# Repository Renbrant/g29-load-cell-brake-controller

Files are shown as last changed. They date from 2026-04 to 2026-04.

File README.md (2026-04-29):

# G29 Load Cell Brake Controller (G29PB v2.0)

A high-performance load cell brake upgrade for the Logitech G29, designed to deliver realistic, pressure-based braking with precision, consistency, and adjustability.

<p align="center">
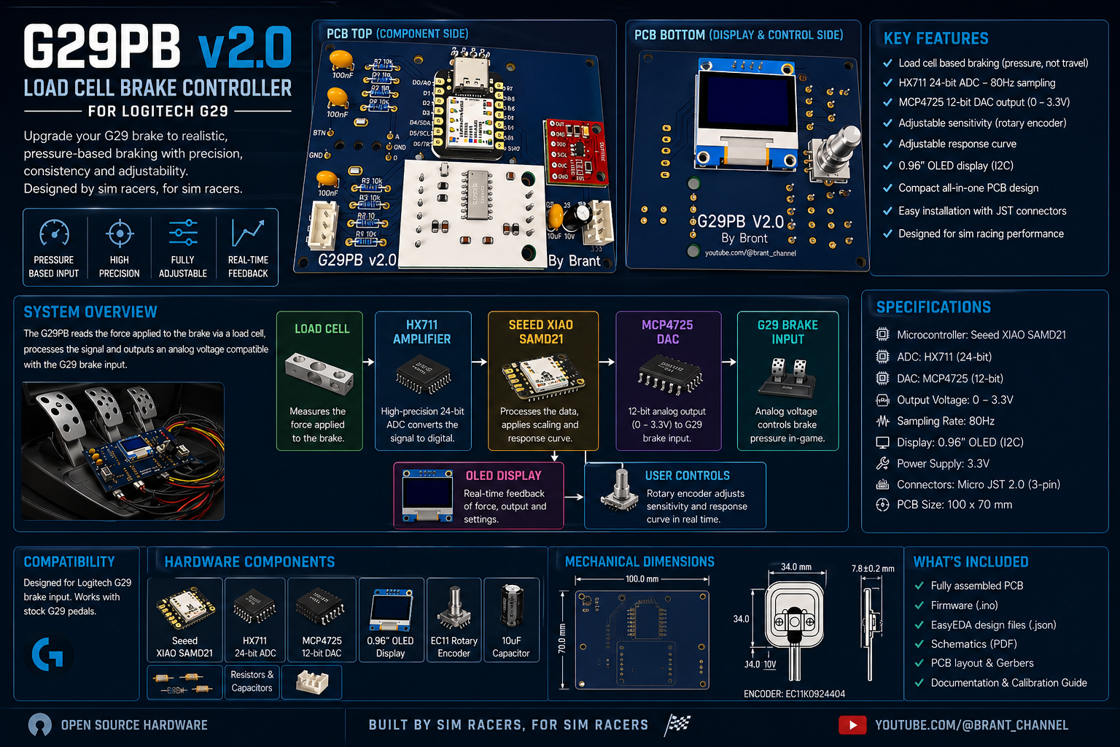
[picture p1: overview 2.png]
  
</p>

---

## 🚀 Overview

The G29PB replaces the stock potentiometer-based brake with a load cell system, transforming braking from position-based input into pressure-based control.

This results in:

* More realistic braking feel
* Better consistency lap after lap
* Improved muscle memory and control

---

## 📸 Hardware

<p align="center">
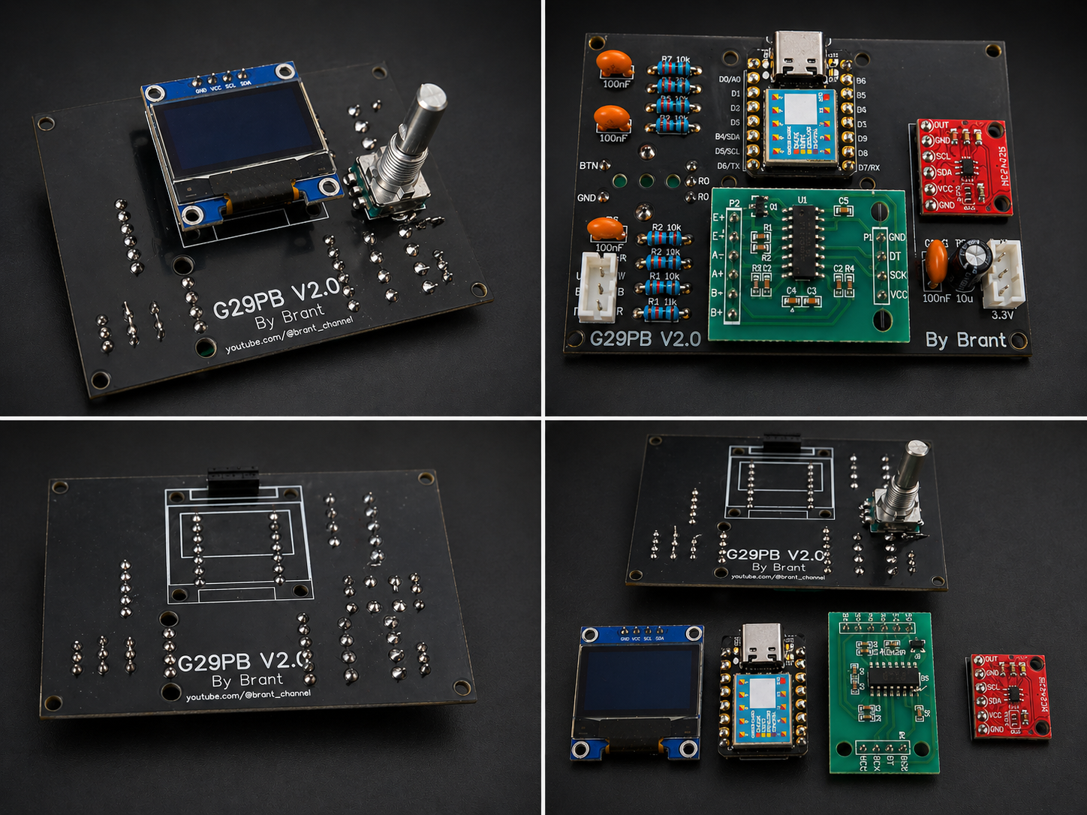
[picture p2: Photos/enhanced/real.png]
  
</p>

### PCB Top Layer

<p align="center">
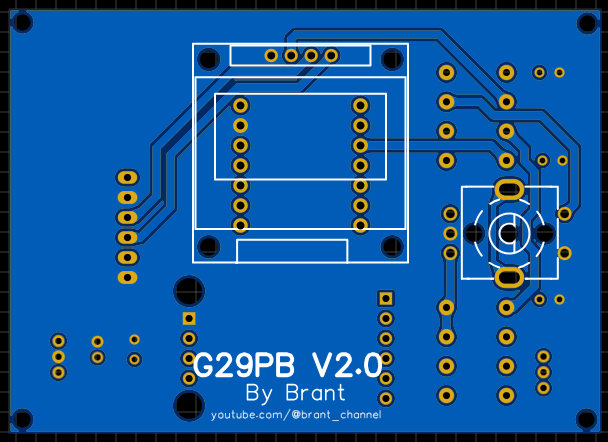
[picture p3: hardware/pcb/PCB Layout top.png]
  
</p>

### PCB Bottom Layer

<p align="center">
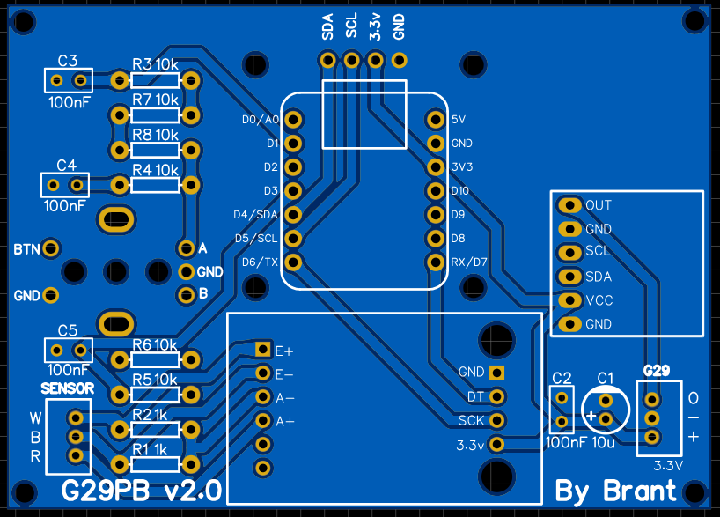
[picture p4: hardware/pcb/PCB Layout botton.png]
  
</p>

---

## 🔥 Key Features

* Load cell-based braking (pressure instead of travel)
* HX711 amplifier with high-speed sampling (80Hz)
* 12-bit analog output via MCP4725 DAC (0–3.3V)
* Adjustable sensitivity via potentiometer
* Adjustable response curve shaping
* Real-time feedback via OLED display
* Compact all-in-one PCB design
* Clean wiring with dedicated connectors

---

## 🧰 Hardware Architecture

* Arduino Nano
* HX711 Load Cell Amplifier
* MCP4725 DAC
* 128x64 OLED Display (I2C)
* Potentiometers:

  * Sensitivity adjustment
  * Curve shaping

---

## 🧠 Design Philosophy

This project prioritizes:

* Fast response over extreme precision
* Driver consistency over raw measurement accuracy
* Simple and reliable calibration
* Hardware-based adjustments (no need to reflash firmware)

---

## 🔌 PCB Design

* Version: **G29PB v2.0**
* Compact and integration-friendly layout
* Optimized routing for signal stability
* Decoupling capacitors for noise reduction
* Dedicated connectors for easy installation

---

## ⚙️ Firmware

Located in `/firmware`

Main features:

* Real-time load cell reading (80Hz)
* Dynamic scaling of input force
* DAC output mapping (0–3.3V)
* Adjustable behavior via potentiometers
* OLED visualization of braking response

---

## 🧪 Calibration

See `/calibration/procedures.md`

Highlights:

* Repeatable manual calibration process
* Stable readings prioritized over absolute precision
* No EEPROM dependency (simplified system)

---

## 🧩 3D Printed Load Cell Adapter

To properly integrate the load cell into the G29 pedal, a custom 3D-printed adapter is used.

<p align="center">
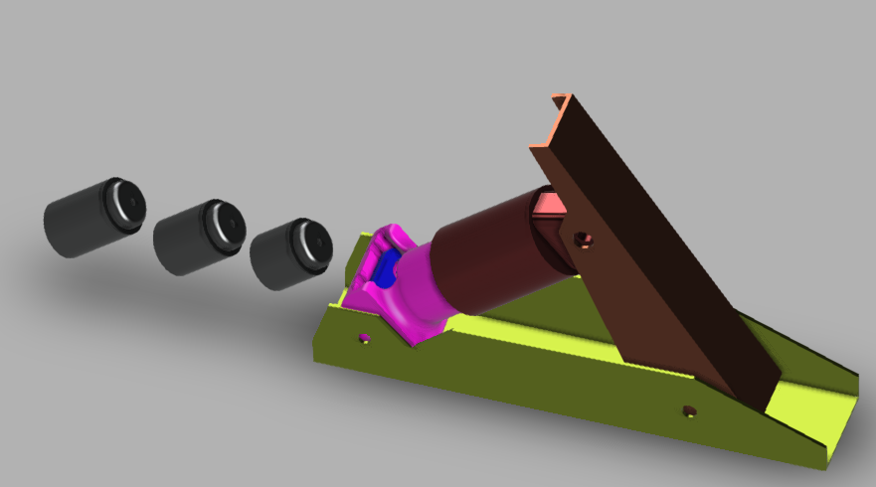
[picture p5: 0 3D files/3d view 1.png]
  
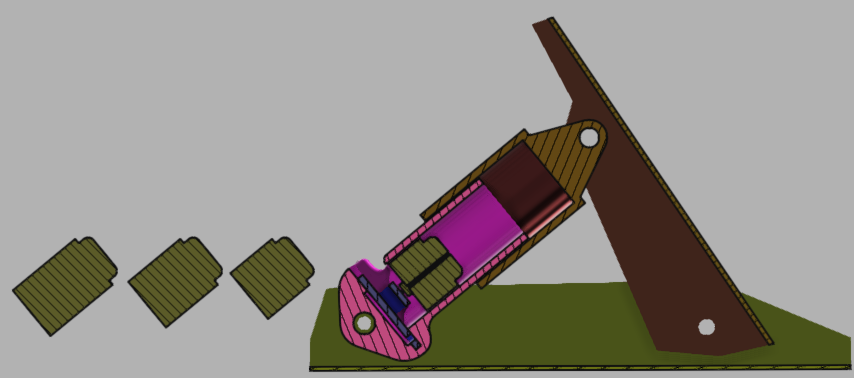
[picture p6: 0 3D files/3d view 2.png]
  
</p>

<p align="center">
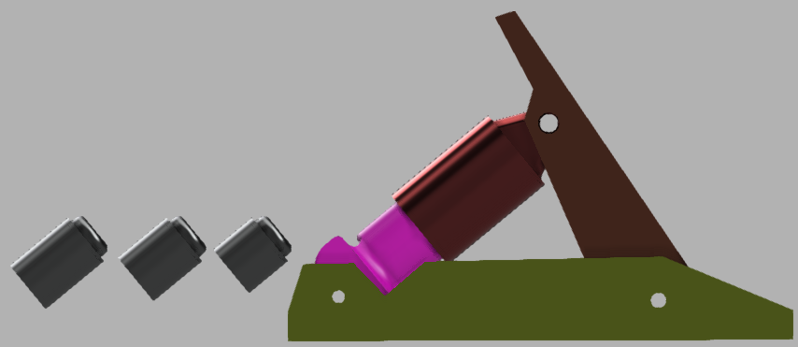
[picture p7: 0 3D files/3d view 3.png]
  
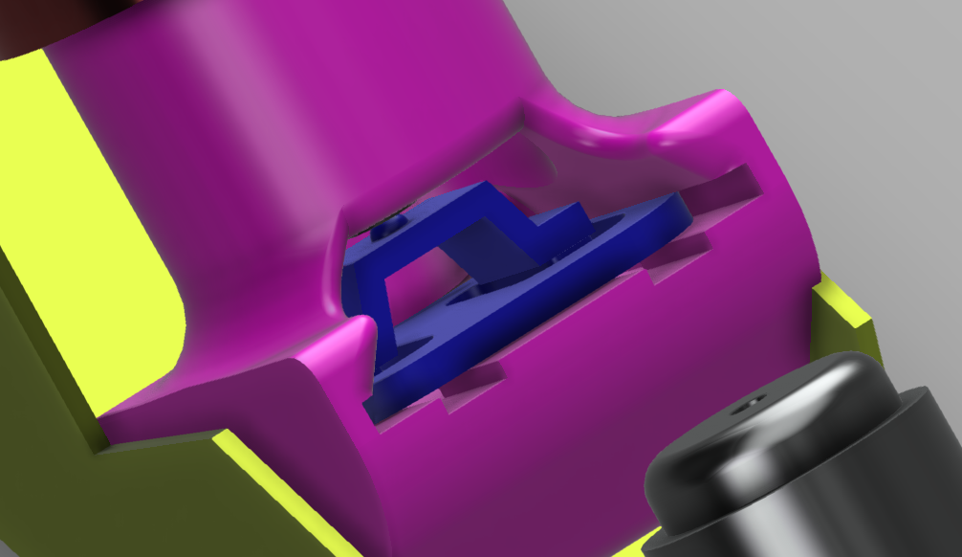
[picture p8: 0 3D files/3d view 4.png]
  
</p>

### 🖨️ 3D Printing Files

All STL files required for printing are available in:

```
/0 3D files/
```

---

## 📦 Repository Contents

* Firmware source code (.ino)
* EasyEDA design files (.json)
* Schematics (PDF)
* PCB layout and Gerbers
* 3D models and STL files
* Documentation and calibration guide

---

## 🎯 Use Case

Designed for sim racers who want:

* Realistic braking feel
* Better trail braking control
* Consistency under pressure
* A DIY solution with professional-level performance

---

## 🤝 Contributing

Contributions are welcome.
Feel free to fork, improve, and share your version.

---

## 📄 License

Licensed under the Apache License 2.0

---

## ❤️ Support the Project

If you found this project useful, consider supporting:

* Subscribe: https://youtube.com/@brant_channel
* Share your build with the community

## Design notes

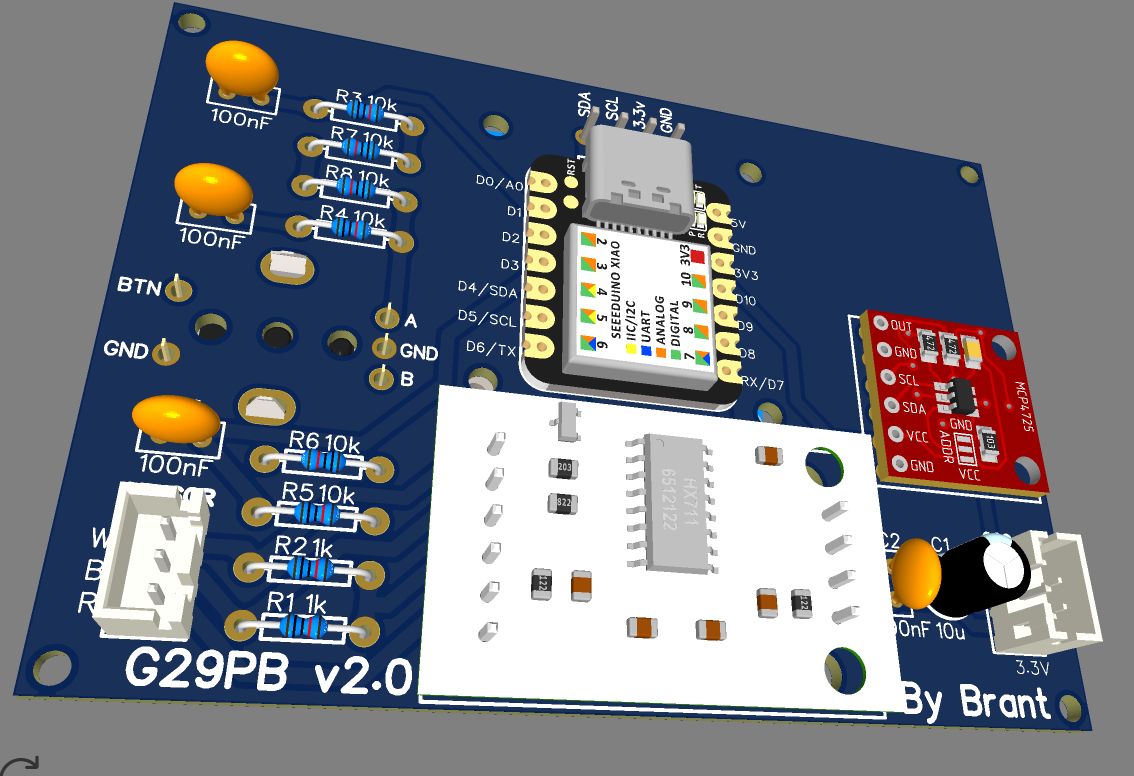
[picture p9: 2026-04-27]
hardware/pcb/PCB 3d view 1.png

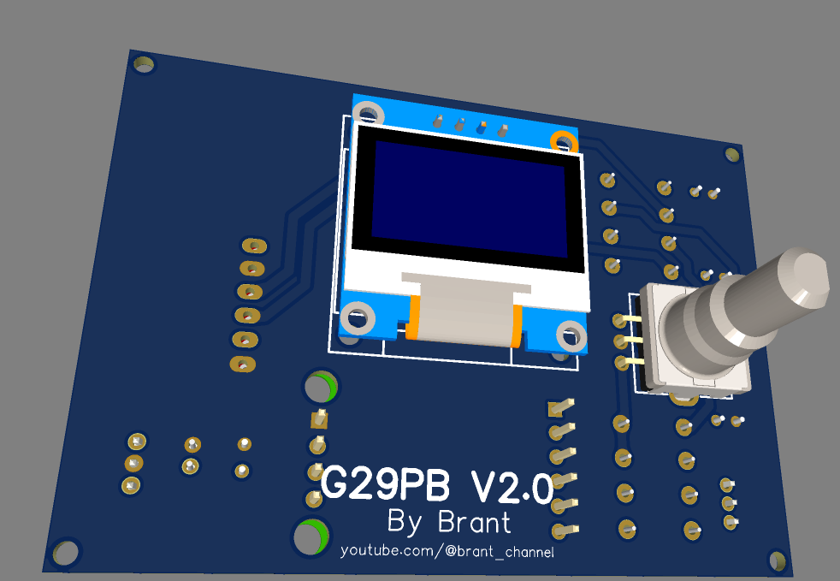
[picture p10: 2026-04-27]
hardware/pcb/PCB 3d view 2.png

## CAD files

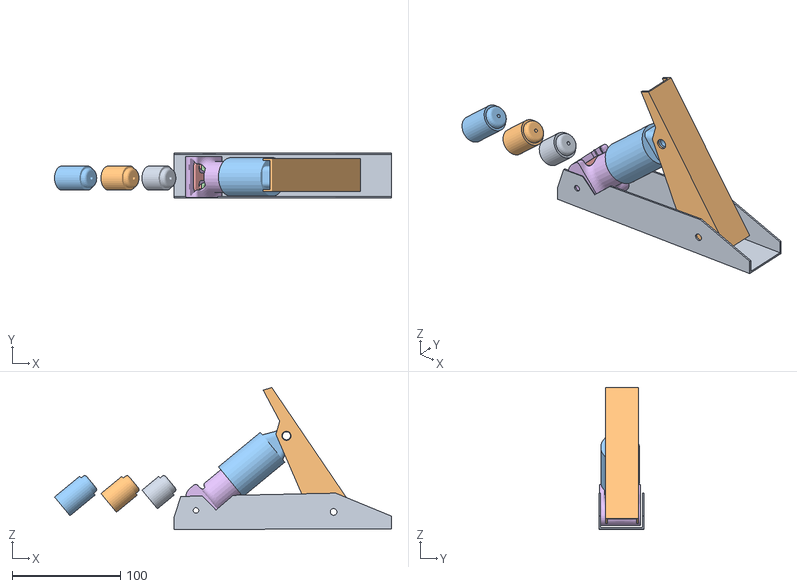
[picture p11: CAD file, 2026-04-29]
0 3D files/G29BS.obj
311.0 x 41.9 x 131.0
50kg load cell (1)
50kg load cell (1) (1)

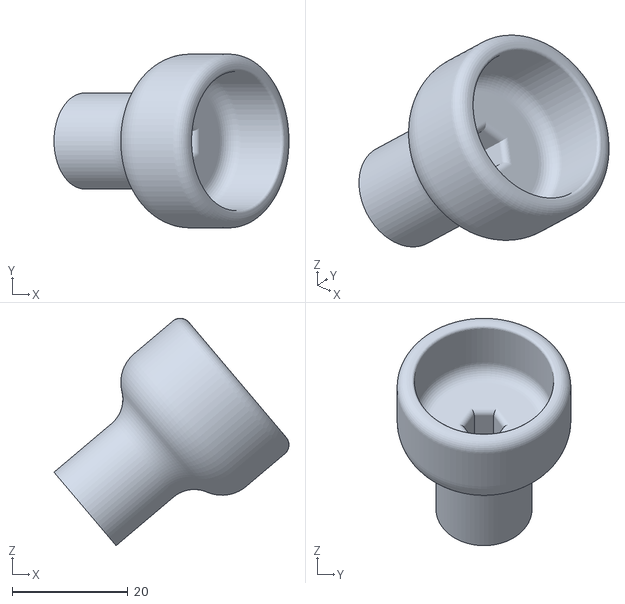
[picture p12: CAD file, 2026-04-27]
0 3D files/Pistao interno v2.stl
40.6 x 30.0 x 39.2

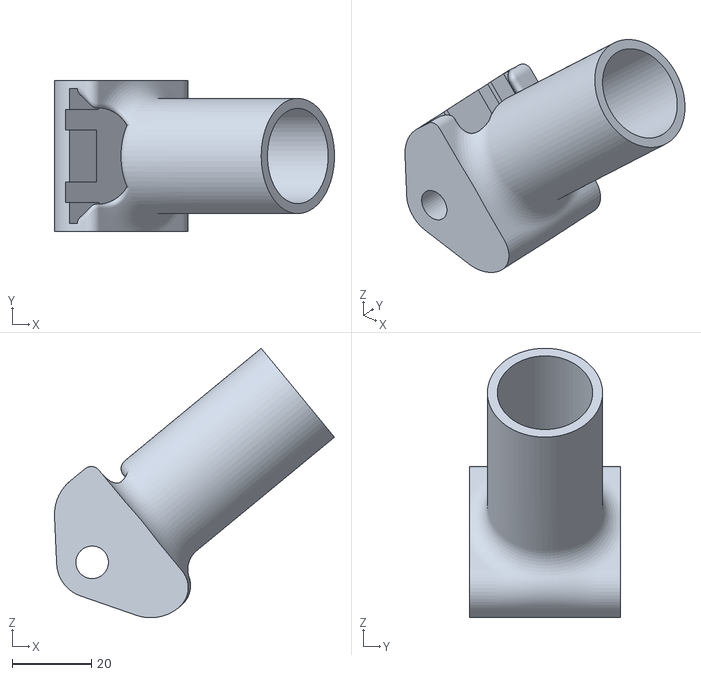
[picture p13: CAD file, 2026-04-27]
0 3D files/Porta sensor v3.stl
70.5 x 38.0 x 67.8

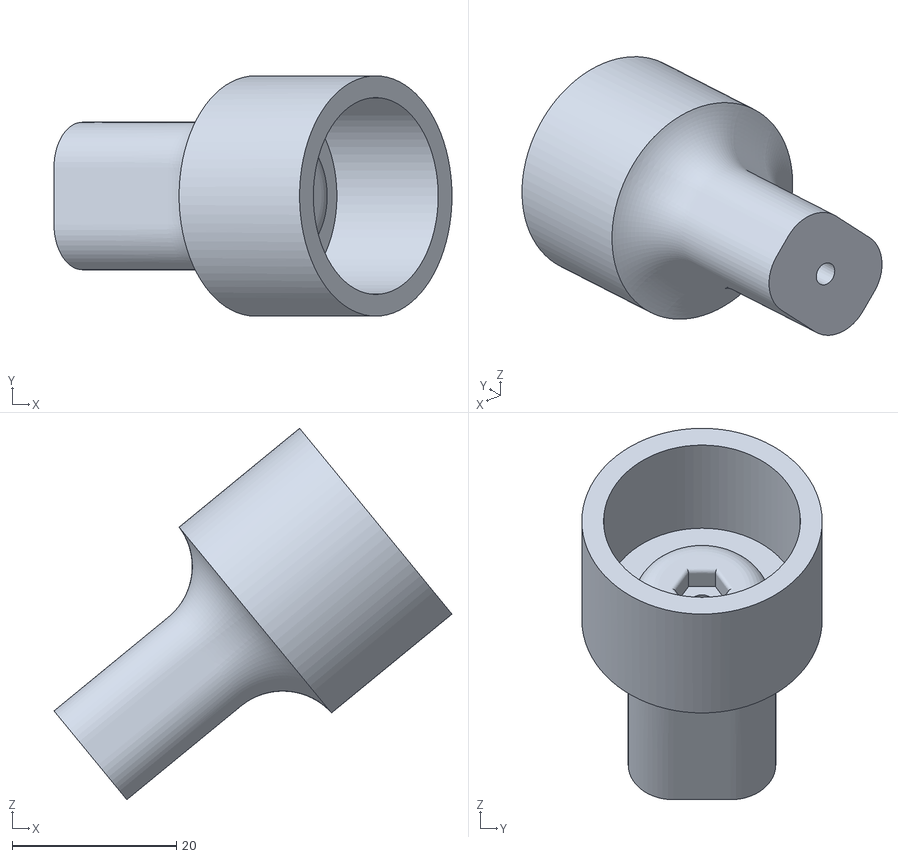
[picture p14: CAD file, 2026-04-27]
0 3D files/Cilindro central.stl
48.5 x 29.3 x 45.3

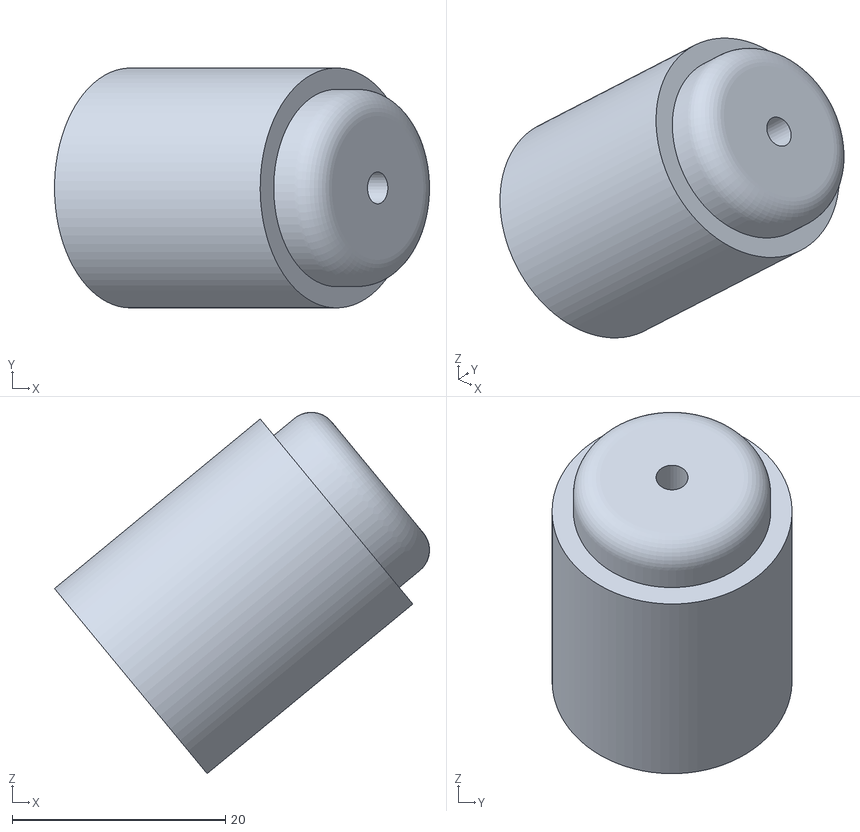
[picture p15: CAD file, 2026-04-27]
0 3D files/Pistao c v3.stl
35.2 x 22.5 x 33.9

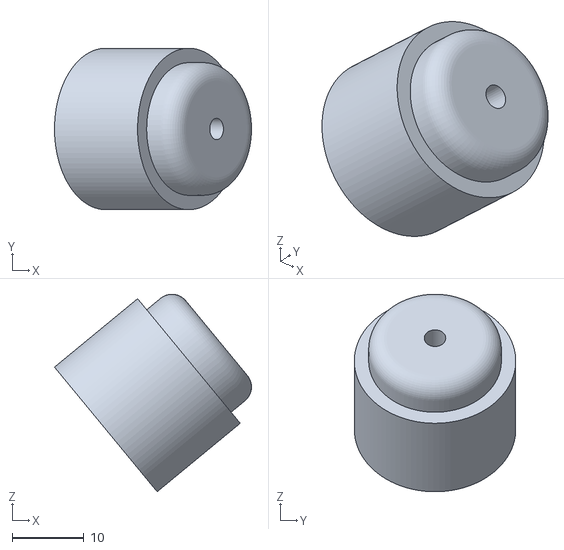
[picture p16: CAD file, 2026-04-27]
0 3D files/Pistao a v3.stl
27.5 x 22.5 x 27.5

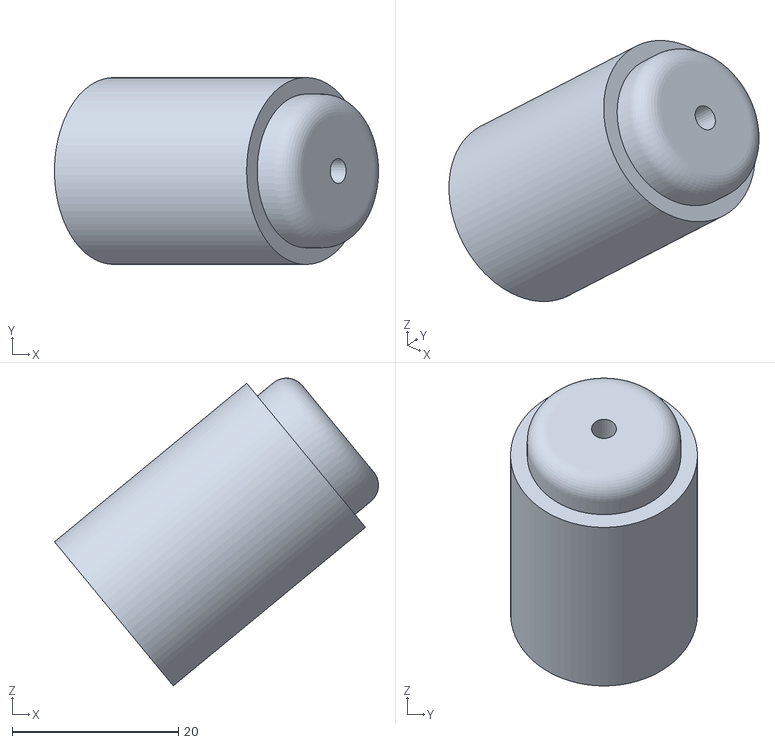
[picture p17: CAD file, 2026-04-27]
0 3D files/Pistao d v3.stl
39.0 x 22.5 x 37.1

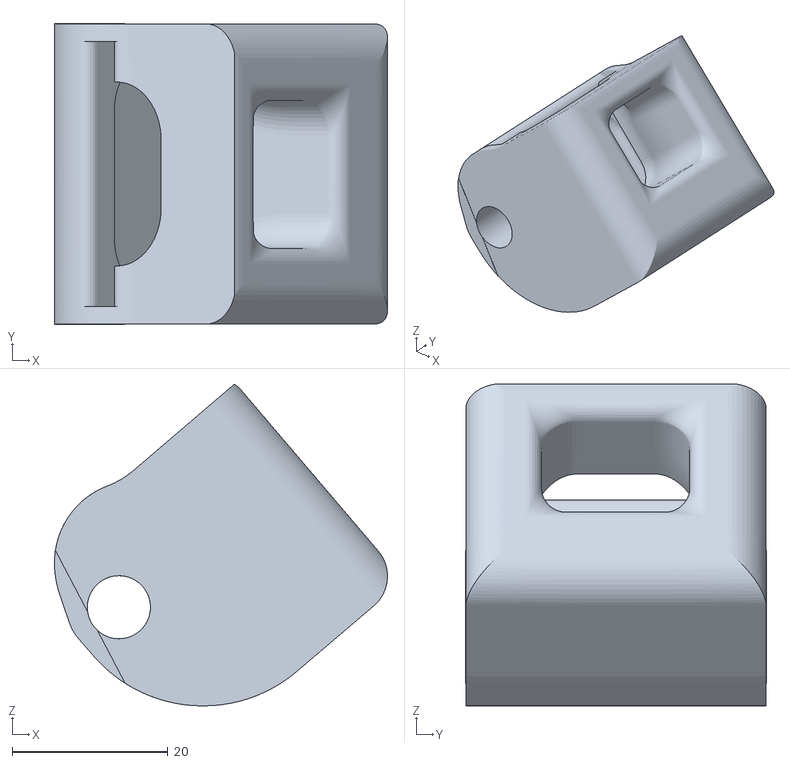
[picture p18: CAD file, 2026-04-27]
0 3D files/Porta sensor.stl
42.7 x 38.6 x 41.3

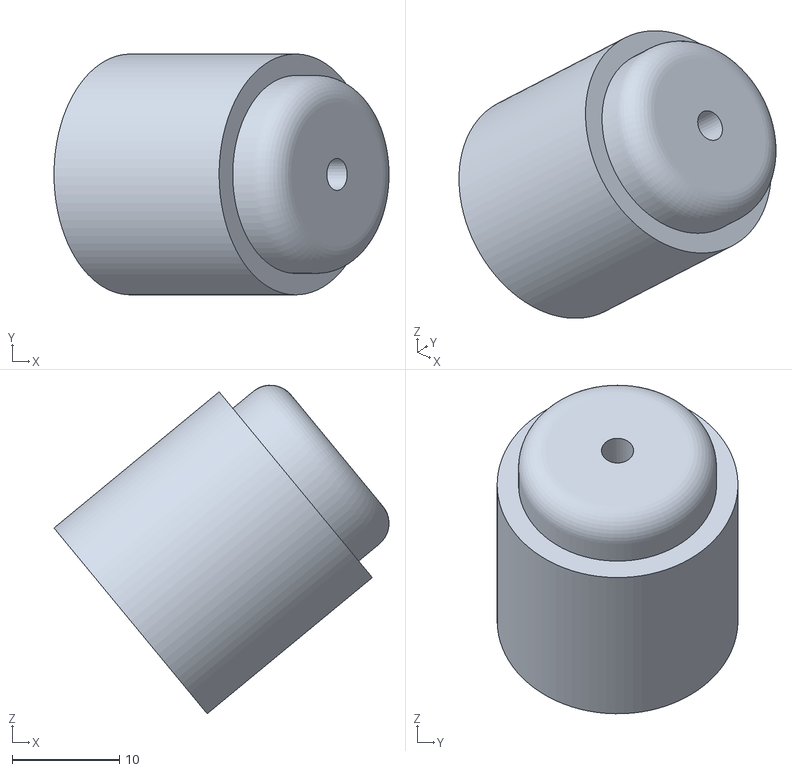
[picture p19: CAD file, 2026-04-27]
0 3D files/Pistao b v3.stl
31.3 x 22.5 x 30.7

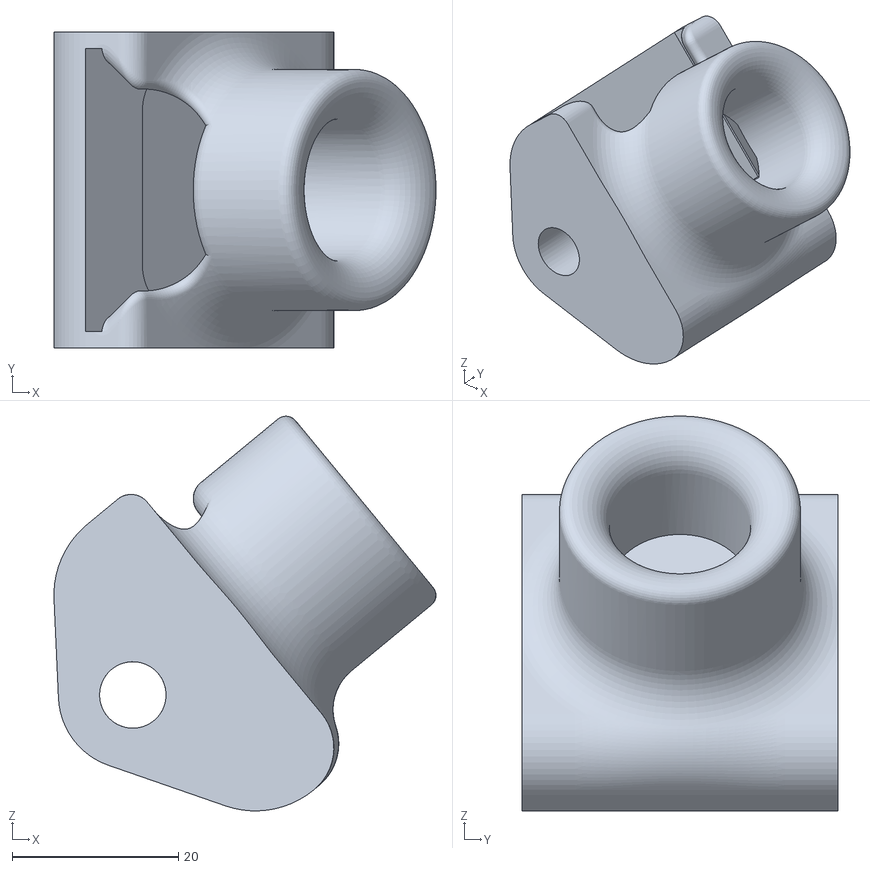
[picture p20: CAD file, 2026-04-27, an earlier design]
0 3D files/Porta sensor v2.stl
45.9 x 38.0 x 47.5

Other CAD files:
0 3D files/Porta sensor (1).stl
0 3D files/G29BS.f3d
0 3D files/Pistao interno v2.f3d
0 3D files/Porta sensor v2.f3d
0 3D files/rear_wheel_axle (1).f3d

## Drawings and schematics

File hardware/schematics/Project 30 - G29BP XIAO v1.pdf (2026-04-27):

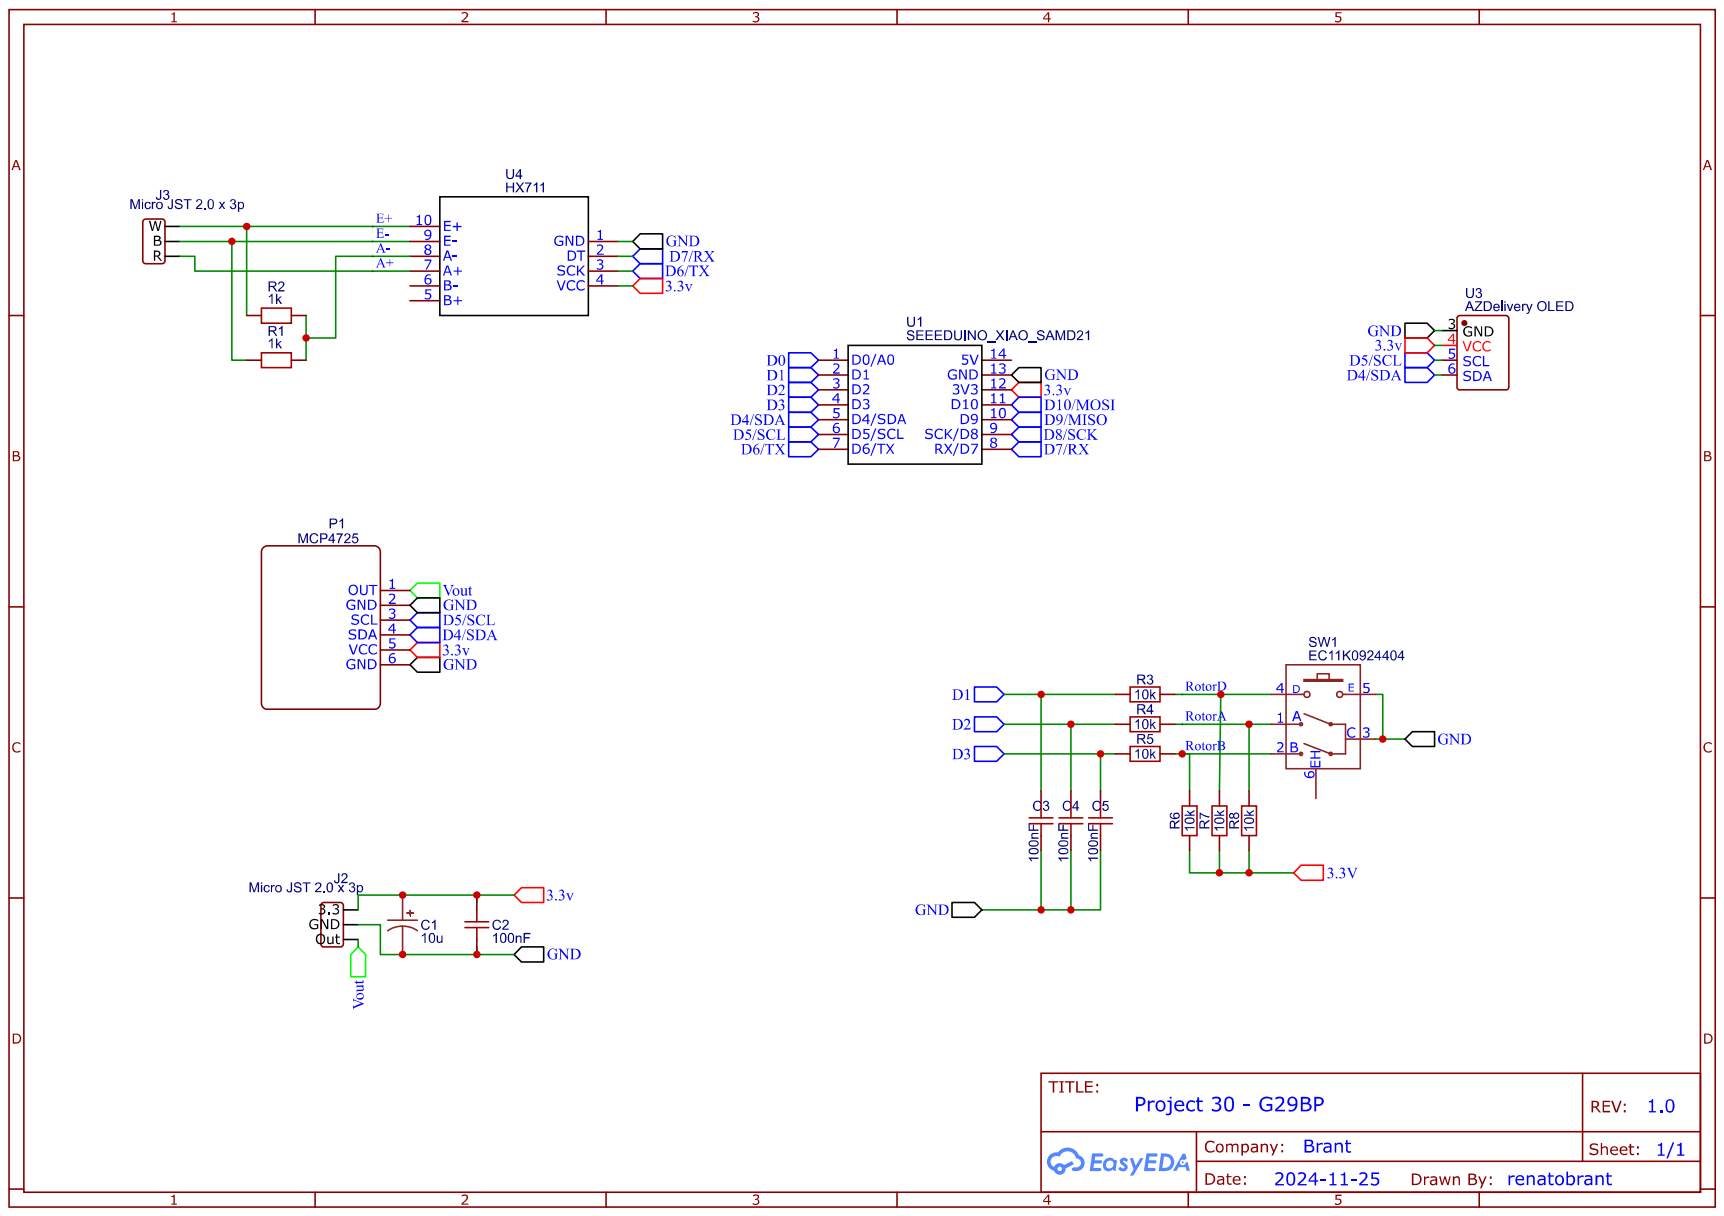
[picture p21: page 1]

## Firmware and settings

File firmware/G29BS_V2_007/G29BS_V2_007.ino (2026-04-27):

/*
  Programa: Simulador de Freio com Saída Analógica
  Autor: Renato Brant
  Data: 01/12/2024
  Versão: v2.007

  Histórico de Modificações:
  - v2.004: Alterado o comportamento do cálculo de curva de tensão para inverter a relação pressão/tensão.
  - v2.005: Corrigido o problema de apresentação do gráfico que ignorava o MIN_VOLTAGE (1.47V).
           Excluída a configuração do formato da curva devido a inconsistências. Agora o comportamento é estritamente linear.
           Criado um histórico de modificações para acompanhamento de versões.
  - v2.006: Refatoração para melhorar a organização e legibilidade do código sem alterar funcionalidades existentes.
           Adicionado ajuste do valor mínimo de tensão (Vmin).
           Valores de Vmax e Vmin exibidos no display (canto inferior esquerdo e superior direito, respectivamente).
           Quadrado desenhado ao redor do valor que está sendo configurado.
           Movida a apresentação da pressão para o canto inferior direito, acima do valor de tensão (previousVoltage).
           Fundo preto adicionado para os valores de pressão e tensão para melhor contraste.
  - v2.007: Melhorada a interface gráfica do ajuste de configurações.
           Menu de configurações exibido no canto superior esquerdo apenas quando o botão é pressionado.
           Opções: Inclinação (I), Vmax e Vmin, com destaque `>` para a configuração ativa.
           Menu desaparece automaticamente após 5 segundos de inatividade, salvando as configurações.
           Corrigido valor no display para sincronizar com a saída DAC.
           Expandido o controle de curva para maior sensibilidade a pressões menores (curva mais inclinada).
*/

#include <Wire.h>
#include <Adafruit_MCP4725.h>
#include <HX711.h>
#include <Adafruit_GFX.h>
#include <Adafruit_SSD1306.h>
#include <Encoder.h>
#include <FlashStorage.h>

// Definições dos pinos
#define DT_PIN 7
#define SCK_PIN 6
#define ROTARY_CLK_PIN 1
#define ROTARY_DT_PIN 2
#define ROTARY_SW_PIN 3
#define OLED_RESET -1

// Objetos para os periféricos
HX711 scale;
Adafruit_MCP4725 dac;
Adafruit_SSD1306 display(128, 64, &Wire, OLED_RESET);
Encoder rotaryEncoder(ROTARY_CLK_PIN, ROTARY_DT_PIN);

// Estrutura para armazenar configurações
struct Config {
  float maxVoltage;  // Tensão máxima ajustável
  float minVoltage;  // Tensão mínima ajustável
  float curveFactor; // Fator de inclinação da curva
};
FlashStorage(flashConfig, Config); // Aloca espaço na memória flash

// Configurações iniciais padrão
float maxVoltage = 3.3;           // Tensão máxima inicial
float minVoltage = 1.47;          // Tensão mínima inicial
float curveFactor = 0.0;          // Inclinação inicial da curva
int lastEncoderPosition = 0;      // Última posição do encoder
bool buttonPressed = false;       // Estado do botão do encoder
int configMode = 0;               // 0 = Inclinação, 1 = Vmax, 2 = Vmin

// Configuração do HX711
const float CALIBRATION_FACTOR = -44.765419; // Fator de calibração para o sensor
const long OFFSET = 1877599;                 // Offset para ajustar o zero
float pressure = 0;                          // Pressão medida em kg

// Controle gráfico
const int GRAPH_WIDTH = 122;                 // Largura do gráfico
const int GRAPH_HEIGHT = 64;                 // Altura do gráfico

float outputVoltage = 0;                     // Tensão de saída calculada

// Controle do menu de configurações
bool showConfigMenu = false;                 // Controla a exibição do menu de configurações
unsigned long lastInteraction = 0;           // Tempo da última interação
const unsigned long CONFIG_TIMEOUT = 5000;   // Tempo limite para esconder o menu (5 segundos)

// Função: Configuração inicial do sistema
void setup() {
  Serial.begin(115200);
  Serial.println("Iniciando sistema...");

  // Inicializa HX711
  scale.begin(DT_PIN, SCK_PIN);
  scale.set_offset(OFFSET);
  scale.set_scale(CALIBRATION_FACTOR);

  // Inicializa DAC MCP4725
  dac.begin(0x60);

  // Inicializa display OLED
  display.begin(SSD1306_SWITCHCAPVCC, 0x3C);
  display.clearDisplay();
  display.setTextSize(1);
  display.setTextColor(WHITE);
  display.display();

  // Configura botão do encoder
  pinMode(ROTARY_SW_PIN, INPUT_PULLUP);

  // Carrega configurações salvas na memória flash
  loadSettings();

  Serial.println("Sistema inicializado com sucesso!");
}

// Função: Laço principal do programa
void loop() {
  handleButtonPress();     // Gerencia as interações do botão
  handleEncoderRotation(); // Processa a movimentação do encoder

  // Esconde o menu de configuração após o tempo limite
  if (showConfigMenu && millis() - lastInteraction > CONFIG_TIMEOUT) {
    showConfigMenu = false;
    saveSettings();
    Serial.println("Configurações salvas automaticamente após inatividade.");
  }

  // Lê e atualiza os dados do sistema
  if (scale.is_ready()) {
    pressure = readPressure(); // Lê a pressão do sensor
    updateDAC();               // Atualiza a saída do DAC
    updateDisplay();           // Atualiza a tela OLED
  }
}

// Função: Lê o estado do botão do encoder
void handleButtonPress() {
  bool currentButtonState = digitalRead(ROTARY_SW_PIN) == LOW;
  if (currentButtonState && !buttonPressed) {
    if (!showConfigMenu) {
      showConfigMenu = true; // Ativa o menu de configurações
    } else {
      configMode = (configMode + 1) % 3; // Alterna entre Inclinação, Vmax e Vmin
    }
    lastInteraction = millis(); // Atualiza o tempo de interação
  }
  buttonPressed = currentButtonState;
}

// Função: Lê o movimento do encoder e ajusta as configurações
void handleEncoderRotation() {
  if (showConfigMenu) { // Permite ajustes apenas quando o menu está ativo
    int newEncoderPosition = rotaryEncoder.read() / 2; // Divide por 2 para maior controle
    if (newEncoderPosition != lastEncoderPosition) {
      int delta = newEncoderPosition - lastEncoderPosition;

      if (configMode == 0) { // Ajusta a Inclinação
        curveFactor += delta * 0.05;
        curveFactor = constrain(curveFactor, -2.0, 2.0); // Limites expandidos
      } else if (configMode == 1) { // Ajusta o Vmax
        maxVoltage += delta * 0.05;
        maxVoltage = constrain(maxVoltage, 2.5, 3.3);
      } else if (configMode == 2) { // Ajusta o Vmin
        minVoltage += delta * 0.05;
        minVoltage = constrain(minVoltage, 1.0, maxVoltage - 0.1);
      }

      lastEncoderPosition = newEncoderPosition;
      lastInteraction = millis(); // Atualiza o tempo de interação
    }
  }
}

// Função: Lê a pressão do sensor HX711
float readPressure() {
  float measuredPressure = scale.get_units() / 1000.0; // Converte para kg
  return constrain(measuredPressure, 0.0, 50.0); // Limita a pressão entre 0 e 50 kg
}

// Função: Calcula e aplica a tensão ao DAC
void updateDAC() {
  float normalizedPressure = pressure / 50.0; // Normaliza a pressão (0 a 1)
  normalizedPressure = constrain(normalizedPressure, 0.0, 1.0);

  float adjustedPressure = normalizedPressure * (1.0 + curveFactor);
  adjustedPressure = constrain(adjustedPressure, 0.0, 1.0);

  // Calcula a tensão de saída
  outputVoltage = minVoltage + (1.0 - adjustedPressure) * (maxVoltage - minVoltage);

  // Converte para 12 bits e atualiza o DAC
  uint16_t dacOutput = (uint16_t)((outputVoltage / 3.3) * 4095);
  dac.setVoltage(dacOutput, false);
}

// Função: Atualiza o display OLED com os dados mais recentes
void updateDisplay() {
  display.clearDisplay();
  drawGraph();

  if (showConfigMenu) { // Exibe o menu de configurações, se ativo
    display.setTextSize(1);
    display.setCursor(0, 0);
    display.setTextColor(WHITE);
    display.print(configMode == 0 ? "> I: " : "  I: ");
    display.println(curveFactor, 2);
    display.print(configMode == 1 ? "> Vmax: " : "  Vmax: ");
    display.println(maxVoltage, 2);
    display.print(configMode == 2 ? "> Vmin: " : "  Vmin: ");
    display.println(minVoltage, 2);
  } else { // Exibe os valores principais
    display.setCursor(0, 0);
    display.setTextSize(2);
    display.print(String(pressure, 0));
    display.setTextSize(1);
    display.print("kg");

    display.fillRect(66, 48, 58, 16, BLACK);
    display.setCursor(66, 48);
    display.setTextSize(2);
    display.print(String(outputVoltage, 2));
    display.setTextSize(1);
    display.print("V");
  }

  display.display();
}

// Função: Desenha o gráfico de curva no display
void drawGraph() {
  for (int x = 0; x < GRAPH_WIDTH; x++) {
    float rawPos = (float)x / GRAPH_WIDTH;
    float curveY = rawPos * (1.0 + curveFactor);
    float voltage = minVoltage + curveY * (maxVoltage - minVoltage);
    float normalizedVoltage = (voltage - minVoltage) / (maxVoltage - minVoltage);
    int y = constrain(GRAPH_HEIGHT - (normalizedVoltage * GRAPH_HEIGHT), 0, GRAPH_HEIGHT - 1);

    display.drawPixel(x, y, WHITE);
    if (rawPos <= pressure / 50.0) {
      display.drawLine(x, GRAPH_HEIGHT - 1, x, y, WHITE);
    }
  }
}

// Função: Salva as configurações na memória flash
void saveSettings() {
  Config config = {maxVoltage, minVoltage, curveFactor};
  flashConfig.write(config);
  Serial.println("Configurações salvas na memória flash.");
}

// Função: Carrega as configurações da memória flash
void loadSettings() {
  Config config = flashConfig.read();
  maxVoltage = config.maxVoltage;
  minVoltage = config.minVoltage;
  curveFactor = config.curveFactor;

  if (maxVoltage < 2.5 || maxVoltage > 3.3) maxVoltage = 3.3;
  if (minVoltage < 1.0 || minVoltage >= maxVoltage) minVoltage = 1.47;
  if (curveFactor < -2.0 || curveFactor > 2.0) curveFactor = 0.0;

  Serial.print("Configurações carregadas: Vmax=");
  Serial.print(maxVoltage, 2);
  Serial.print("V, Vmin=");
  Serial.print(minVoltage, 2);
  Serial.print("V, Inclinação=");
  Serial.println(curveFactor, 2);
}

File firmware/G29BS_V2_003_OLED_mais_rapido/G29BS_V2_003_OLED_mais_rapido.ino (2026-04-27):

#include <Wire.h>
#include <Adafruit_MCP4725.h>
#include <HX711.h>
#include <Adafruit_GFX.h>
#include <Adafruit_SSD1306.h>
#include <Encoder.h>
#include <FlashStorage.h> // Substituição da EEPROM

// Definições dos pinos
#define DT_PIN 7
#define SCK_PIN 6
#define ROTARY_CLK_PIN 1
#define ROTARY_DT_PIN 2
#define ROTARY_SW_PIN 3
#define OLED_RESET -1

// Objetos para os periféricos
HX711 scale;
Adafruit_MCP4725 dac;
Adafruit_SSD1306 display(128, 64, &Wire, OLED_RESET);
Encoder rotaryEncoder(ROTARY_CLK_PIN, ROTARY_DT_PIN);

// Estrutura para armazenar configurações
struct Config {
  float maxVoltage;
  float curveFactor;
  float curveShape;
};
FlashStorage(flashConfig, Config); // Aloca espaço na flash

// Configuração inicial
float maxVoltage = 3.3;           // Tensão máxima inicial
float curveFactor = 0.0;          // Fator de curva inicial
float curveShape = 0.0;           // Formato da curva inicial (0 = linear)
int lastEncoderPosition = 0;
bool buttonPressed = false;
int configMode = 0; // 0 = Vmax, 1 = Curva, 2 = Formato da Curva

// Configuração do HX711
const float CALIBRATION_FACTOR = -44.765419; // Fator de calibração
const long OFFSET = 1877599;                 // Offset para zero
float pressure = 0;                          // Pressão medida em kg

// Dados do gráfico
const int GRAPH_WIDTH = 122;      // Largura do gráfico
const int GRAPH_HEIGHT = 64;      // Altura do gráfico
const float MIN_VOLTAGE = 1.47;   // Tensão mínima fixa para o MCP4725

float previousPressure = 0;       // Última pressão registrada para comparação

void setup() {
  Serial.begin(115200);
  Serial.println("Iniciando sistema...");

  // Inicializa HX711
  scale.begin(DT_PIN, SCK_PIN);
  scale.set_offset(OFFSET);
  scale.set_scale(CALIBRATION_FACTOR);

  // Inicializa DAC MCP4725
  dac.begin(0x60);

  // Inicializa display OLED
  display.begin(SSD1306_SWITCHCAPVCC, 0x3C);
  display.clearDisplay();
  display.setTextSize(1);
  display.setTextColor(WHITE);
  display.display();

  // Configura botão do encoder
  pinMode(ROTARY_SW_PIN, INPUT_PULLUP);

  // Carrega configurações da flash
  loadSettings();

  Serial.println("Sistema inicializado com sucesso!");
}

void loop() {
  // Leitura do estado do botão do encoder
  bool currentButtonPressed = digitalRead(ROTARY_SW_PIN) == LOW;
  if (currentButtonPressed && !buttonPressed) {
    configMode = (configMode + 1) % 3; // Alterna entre Vmax, Curva e Formato
    saveSettings(); // Salva as configurações na flash
    Serial.println(configMode == 0 ? "Ajustando Vmax" : configMode == 1 ? "Ajustando Curva" : "Ajustando Formato");
  }
  buttonPressed = currentButtonPressed;

  // Leitura do encoder rotativo
  int newEncoderPosition = rotaryEncoder.read() / 2; // Divide por 2 para maior controle
  if (newEncoderPosition != lastEncoderPosition) {
    int delta = newEncoderPosition - lastEncoderPosition;

    if (configMode == 0) {
      maxVoltage += delta * 0.05; // Incrementa ou decrementa em passos de 0.05
      maxVoltage = constrain(maxVoltage, 2.5, 3.3);
    } else if (configMode == 1) {
      curveFactor += delta * 0.01; // Incrementa ou decrementa em passos de 0.01
      curveFactor = constrain(curveFactor, -1.0, 1.0);
    } else if (configMode == 2) {
      curveShape += delta * 0.1; // Incrementa ou decrementa em passos de 0.1
      curveShape = constrain(curveShape, -1.0, 1.0);
    }

    lastEncoderPosition = newEncoderPosition;
  }

  // Leitura da pressão do pedal
  if (scale.is_ready()) {
    pressure = scale.get_units() / 1000.0; // Converte para kg
    pressure = constrain(pressure, 0.0, 50.0); // Limita a pressão entre 0 e 50 kg

    // Atualiza a saída do DAC
    updateDAC();

    // Atualiza o display sincronizado com a leitura
    updateDisplay();
  }
}

void updateDAC() {
  // Normaliza a pressão (0 a 1)
  float normalizedPressure = pressure / 50.0; // Pressão máxima de 50 kg
  normalizedPressure = constrain(normalizedPressure, 0.0, 1.0);

  // Aplica o formato da curva (exponencial ou inversa) mantendo os extremos fixos
  float adjustedPressure;
  if (curveShape > 0) { // Curva convexa (barriguda para cima)
    adjustedPressure = pow(normalizedPressure, 1.0 / (1.0 + curveShape));
  } else if (curveShape < 0) { // Curva côncava (barriguda para baixo)
    adjustedPressure = 1.0 - pow(1.0 - normalizedPressure, 1.0 / (1.0 - curveShape));
  } else { // Curva linear
    adjustedPressure = normalizedPressure;
  }

  // Ajusta o fator de curva
  adjustedPressure *= (1 + curveFactor);
  adjustedPressure = constrain(adjustedPressure, 0.0, 1.0);

  // Calcula a tensão de saída com base em Vmax e pressão ajustada
  float outputVoltage = MIN_VOLTAGE + adjustedPressure * (maxVoltage - MIN_VOLTAGE);

  // Atualiza o DAC apenas se a pressão mudou significativamente
  if (abs(outputVoltage - previousPressure) > 0.01) { // Evita atualizações redundantes
    uint16_t dacOutput = (uint16_t)((outputVoltage / 3.3) * 4095); // Converte para 12 bits
    dac.setVoltage(dacOutput, false);
    previousPressure = outputVoltage; // Atualiza o valor anterior
  }
}

void updateDisplay() {
  display.clearDisplay();

  // Desenha o gráfico
  drawGraph();

  // Exibe o valor de pressão no canto superior esquerdo
  display.setCursor(0, 0);
  display.setTextSize(2);
  display.setTextColor(WHITE, BLACK);
  display.print(pressure, 0);
  display.print("kg");

  // Exibe o valor atual de configuração
  display.setTextSize(1);
  display.setCursor(0, 20);
  if (configMode == 0) {
    display.print("Vmax: ");
    display.print(maxVoltage, 2);
    display.print("V");
  } else if (configMode == 1) {
    display.print("Curva: ");
    display.print(curveFactor, 2);
  } else if (configMode == 2) {
    display.print("Formato: ");
    display.print(curveShape, 2);
  }

  display.display();
}

void drawGraph() {
  for (int x = 0; x < GRAPH_WIDTH; x++) {
    float rawPos = (float)x / GRAPH_WIDTH;
    float curveY;

    // Aplica o formato da curva mantendo os extremos fixos
    if (curveShape > 0) { // Curva convexa
      curveY = pow(rawPos, 1.0 / (1.0 + curveShape));
    } else if (curveShape < 0) { // Curva côncava
      curveY = 1.0 - pow(1.0 - rawPos, 1.0 / (1.0 - curveShape));
    } else { // Curva linear
      curveY = rawPos;
    }

    // Ajusta o fator de curva
    curveY *= (1 + curveFactor);
    curveY = constrain(curveY, 0.0, 1.0);

    int y = constrain(GRAPH_HEIGHT - (curveY * GRAPH_HEIGHT), 0, GRAPH_HEIGHT - 1);

    // Desenha o gráfico
    display.drawPixel(x, y, WHITE);

    // Preenche até o nível correspondente à pressão atual
    if (rawPos <= pressure / 50.0) {
      display.drawLine(x, GRAPH_HEIGHT - 1, x, y, WHITE);
    }
  }
}

void saveSettings() {
  Config config = {maxVoltage, curveFactor, curveShape};
  flashConfig.write(config);
  Serial.println("Configurações salvas na memória flash.");
}
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
